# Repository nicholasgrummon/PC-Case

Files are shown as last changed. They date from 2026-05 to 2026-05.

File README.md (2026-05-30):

# PC Case Design Project

I'm the proud new owner of an RTX 3060 12G that will soon be put to good use for local compute with Ollama and OpenCode. But my Optiplex PC case neither fit the part nor looked the part, so an upgrade was in order.

-DESIGNED in SolidWorks for ease of assembly (no fasteners outside of base for frame), plentiful airflow (FLUENT validation), efficient load transfer (ANSYS study), and - of course - style (cherry featured most prominently).

-BUILT with Dynatorch CNC plasma cutter, Boss laser cutter, Bridgeport mill, Whacheon lathe, Lincoln MIG welder, and Powermatic table saw.

-TESTED with HFS calipers, my trusty multimeter, and a healthy amount of sudo dmesg and update grub.

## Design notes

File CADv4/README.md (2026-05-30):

# CAD v4
The fourth version of the CAD is identical to CADv3, except components and details not necessary for FEA have been removed.
A simplified model is created for both the structural and fluid FEA.
Due to SOLIDWORKS proprietary file system constraints, FreeCAD STEP and IGES files are also included to enable transfer to ANSYS.

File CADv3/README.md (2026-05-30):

# CAD v3
The third version of the CAD finalizes details and actual implementation.
Specific plans are formulated for fabrication and assembly.

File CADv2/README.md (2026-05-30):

# CAD v2
The second version of the CAD focuses on structural implementation and details.
A working frame design is established, but smaller components and assemblies may still lack details.

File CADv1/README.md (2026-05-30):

# CAD v1
The first version of the CAD focuses on high-level communication of design.
Components don't necessarily fit together, but general design vision is captured.

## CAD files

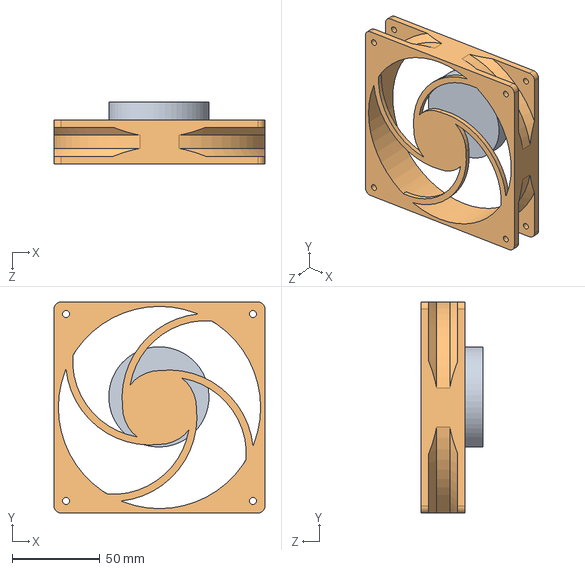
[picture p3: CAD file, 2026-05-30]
CADv3/Fan/FAN.SLDASM
120.0 x 120.0 x 35.0 mm
FAN BODY
fan blades

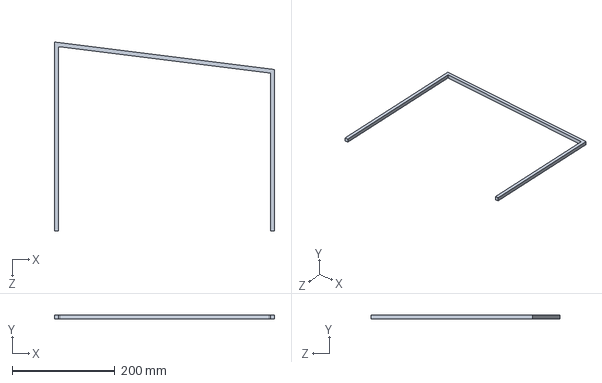
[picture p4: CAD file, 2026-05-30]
CADv1/Wood-slat.SLDPRT
428.6 x 7.94 x 368.2 mm

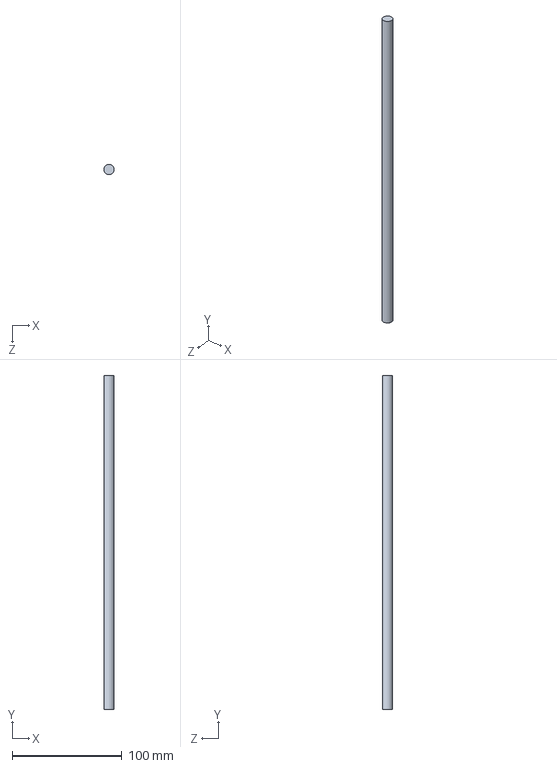
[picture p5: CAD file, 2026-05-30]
CADv2/Rod-mock.SLDPRT
9.51 x 304.8 x 9.53 mm

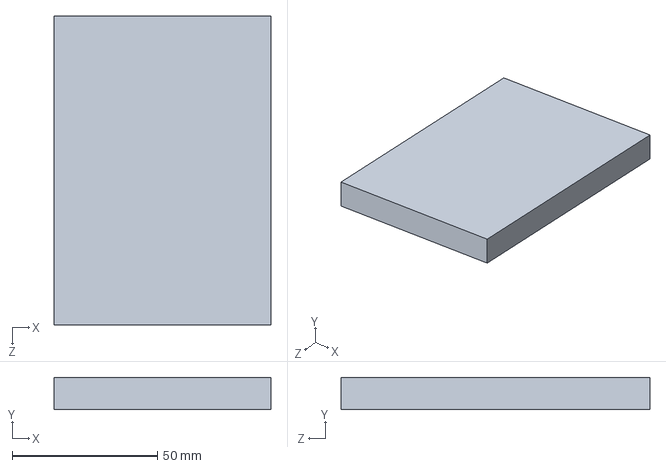
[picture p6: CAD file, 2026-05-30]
CADv3/SSD.SLDPRT
74.6 x 11.1 x 106.4 mm

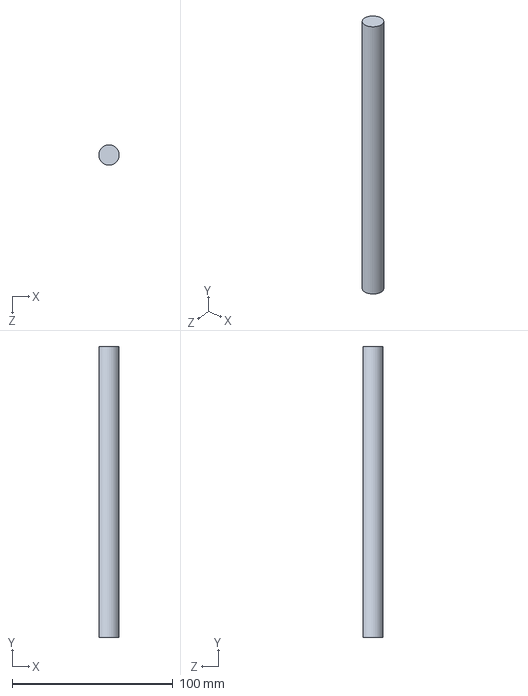
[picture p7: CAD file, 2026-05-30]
CADv4/Handle-rod-smooth.SLDPRT
12.7 x 181.0 x 12.7 mm

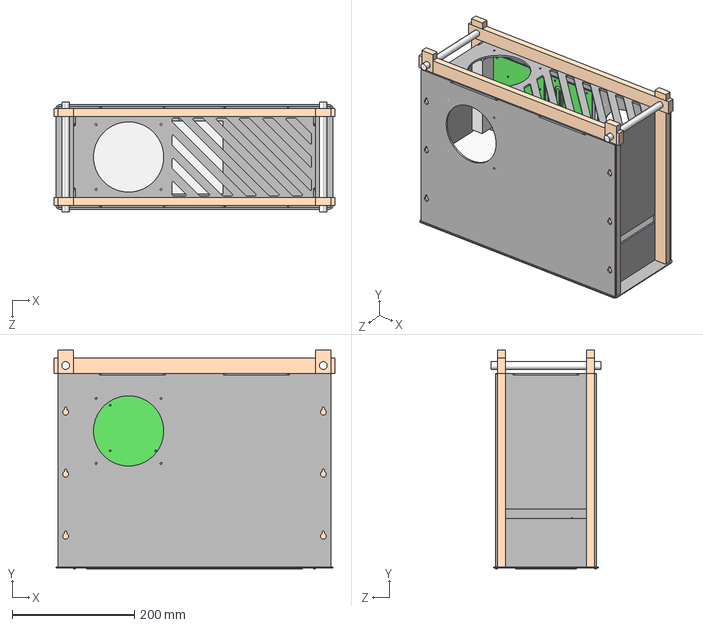
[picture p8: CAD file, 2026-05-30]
FEA/PC-Case4.IGS
460.4 x 358.8 x 181.0 mm

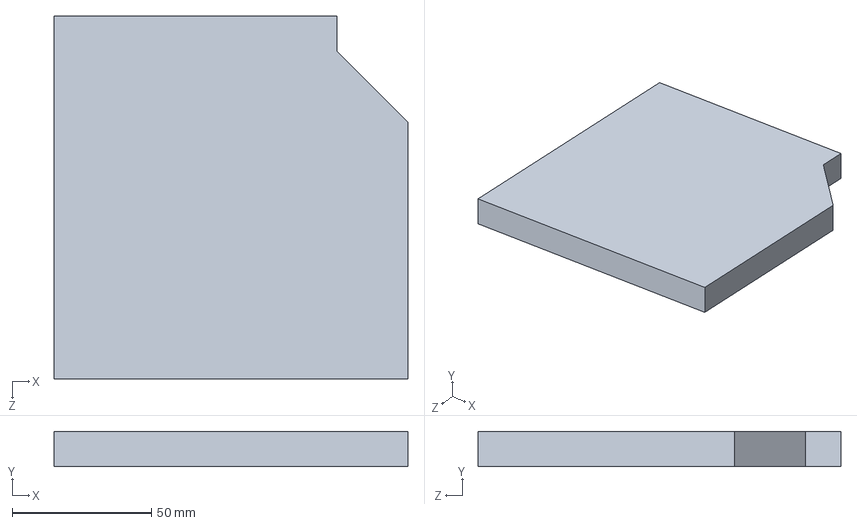
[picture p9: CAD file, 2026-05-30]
CADv1/CD-Drive.SLDPRT
127.0 x 12.7 x 130.2 mm

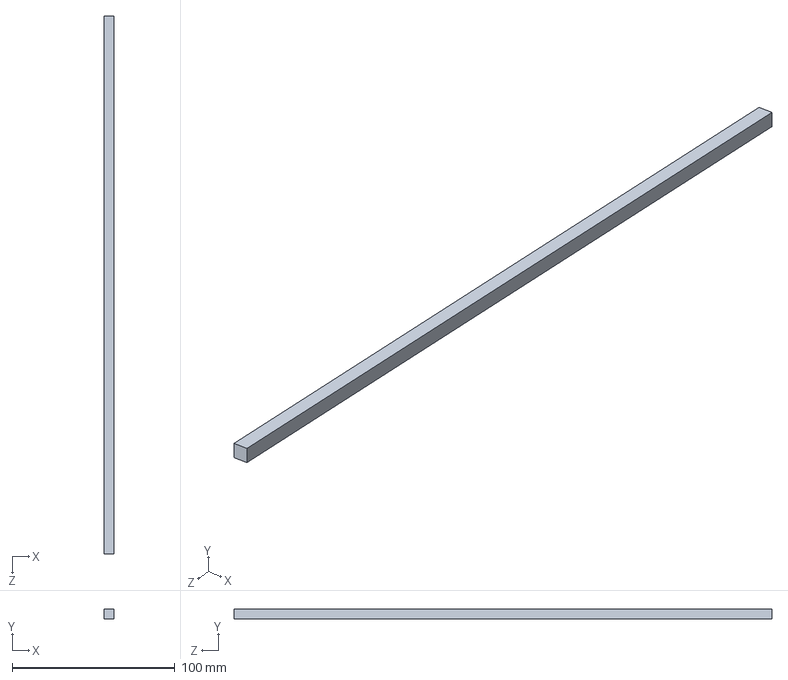
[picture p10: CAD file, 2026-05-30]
CADv2/Motherboard-upright-bracket.SLDPRT
6.35 x 6.35 x 330.2 mm

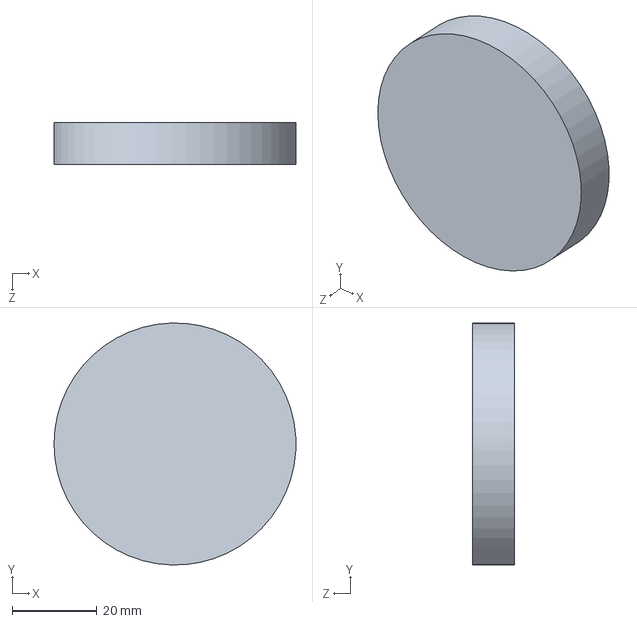
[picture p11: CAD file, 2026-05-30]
CADv3/Fan/FAN BLADES.SLDPRT
57.0 x 57.0 x 10.0 mm

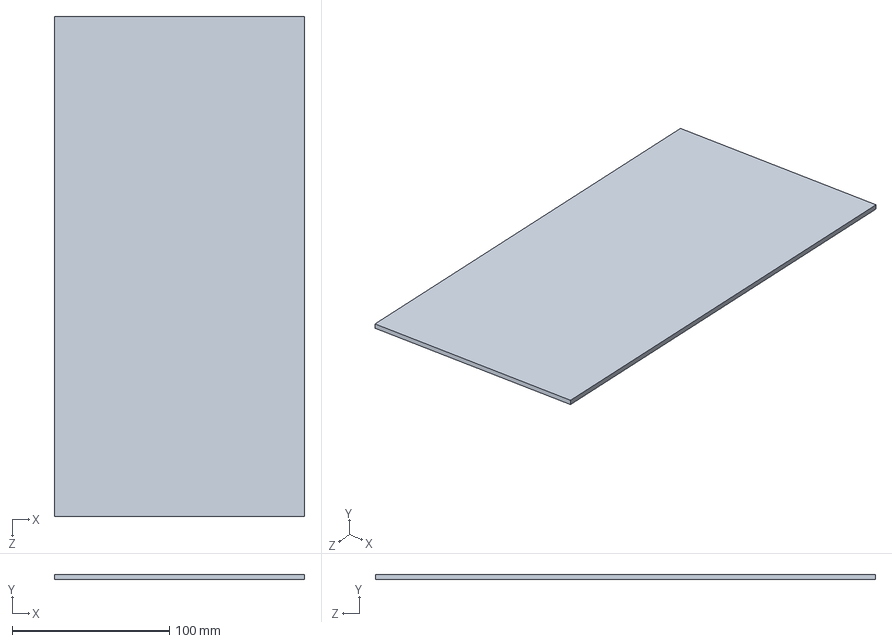
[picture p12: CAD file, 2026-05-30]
CADv4/Interface-panel-simple.SLDPRT
158.8 x 3.17 x 317.5 mm

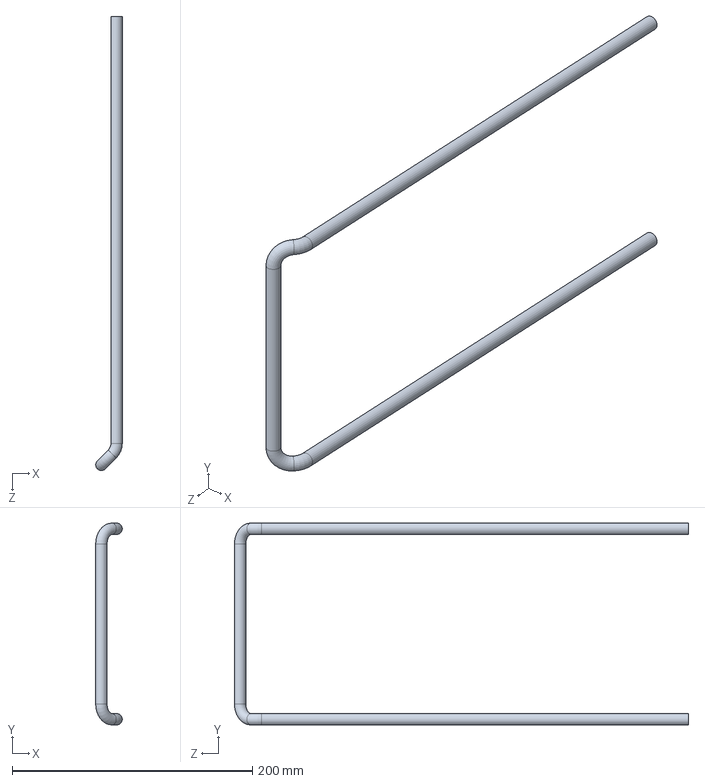
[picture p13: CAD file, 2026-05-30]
CADv1/Tall-frame.SLDPRT
22.2 x 168.3 x 378.3 mm

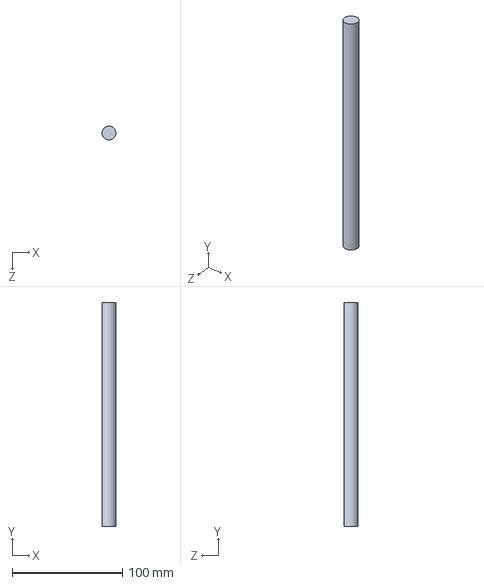
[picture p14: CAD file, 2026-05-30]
CADv2/Handle.SLDPRT
12.7 x 203.2 x 12.7 mm

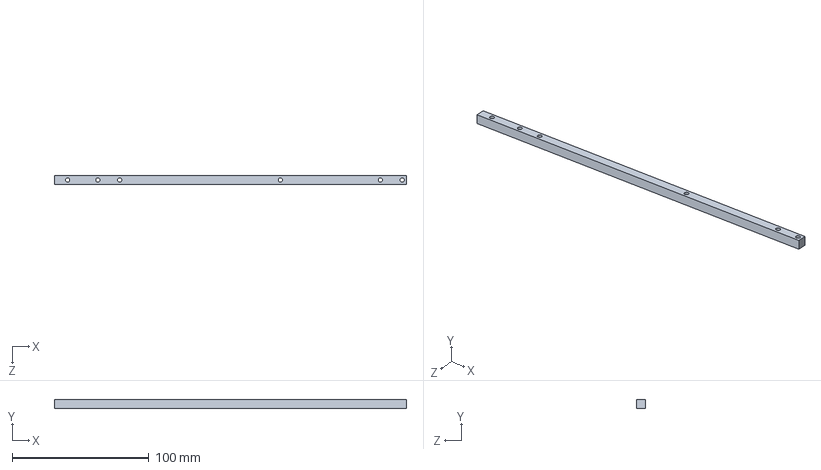
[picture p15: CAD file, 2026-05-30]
CADv3/Bracket-across.SLDPRT
257.2 x 6.35 x 6.35 mm

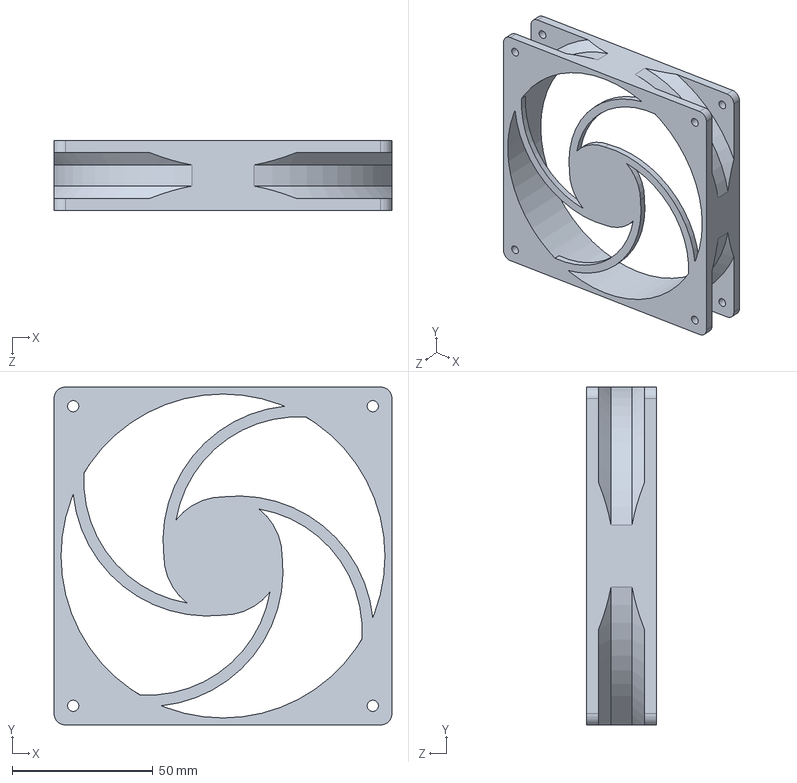
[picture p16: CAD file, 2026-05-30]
CADv3/Fan/FAN BODY.SLDPRT
120.0 x 120.0 x 25.0 mm

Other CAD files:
CADv3/PC-Case3.SLDASM
CADv2/Frame-mock.SLDASM
CADv1/PC-Case.SLDASM
CADv1/Acrylic-layout.SLDASM
CADv1/Back-panel.SLDPRT
CADv1/Base-plate.SLDPRT
CADv1/Front-panel.SLDPRT
CADv1/Hard-drive.SLDPRT
CADv1/Motherboard.SLDPRT
CADv1/PSU.SLDPRT
CADv1/SSD.SLDPRT
CADv1/Short-frame.SLDPRT
CADv1/Short-panel.SLDPRT
CADv1/Tall-panel.SLDPRT
CADv2/Corner-slat.SLDPRT
CADv2/GPU-Post.SLDPRT
CADv2/Hardware-Tray.SLDPRT
CADv2/Lbracket-short.SLDPRT
CADv2/Motherboard-across-bracket.SLDPRT
CADv2/Wood-slat.SLDPRT
CADv3/91070A261_Rounded Head Screws for Plywood and OSB.SLDPRT
CADv3/98335A135_Zinc-Plated Spring Steel Cotter Pin.SLDPRT
CADv3/Back-panel.SLDPRT
CADv3/Base-plate.SLDPRT
CADv3/Bottom-brace.SLDPRT
CADv3/Bracket-upright.SLDPRT
CADv3/CD-Drive.SLDPRT
CADv3/Frame-across.SLDPRT
CADv3/Frame-upright.SLDPRT
CADv3/Front-panel.SLDPRT
CADv3/GPU-support.SLDPRT
CADv3/GPU.SLDPRT
CADv3/Handle-rod.SLDPRT
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

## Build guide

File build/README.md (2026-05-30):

# Build Process
This folder features photos of the build process which was conducted as follows:
1. Cut frame pieces from cherry boards using table saw and miter saw
2. Cut base plate using plasma cutter
3. Weld supporting braces to bottom of base plate to mitigate bending
4. Laser cut acrylic side panels
5. Mill brackets to hold motherboard
6. Assemble frame and hang motherboard
7. Lathe standoffs and plasma cut hardware trays for disc drives
8. Complete detailing of panels with cherry slats
9. Assemble and wire components in case

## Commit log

2026-05-30 Add CADv4 folder
    Updated README to reflect changes in CAD version.
2026-05-30 CADv4 (for FEA)
    [Air-volume.SLDPRT, Back-panel-simple.SLDPRT, Base-plate-simple.SLDPRT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]
